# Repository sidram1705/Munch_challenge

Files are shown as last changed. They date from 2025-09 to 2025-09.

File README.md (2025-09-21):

# Munch_challenge

## Progress date: 14 Sept

### 1. Breadboard Circuit Assembly

After reviewing the datasheets of the motor driver and stm nucleo board, I noted the power requirements and pins that can be connected according to these requirements. This was the setup implemented by me:

| Pins | Connection | Reasoning |
| --- | --- | ---|
| EN | PA7 (STM32) | Enable pin just needs a digital High/Low, something we need to turn on and off the stepper motor to our exact rotation |
| MS1 | VCCIO (STM32) | The microstep pin connection would determines the multiplier for the angle of rotation. I decided to go with 16X by connecting both the pins to 5V|
| MS2 | VCCIO (STM32) | The microstep pin connection would determines the multiplier for the angle of rotation. I decided to go with 16X by connecting both the pins to 5V |
| Rx | x | Left floating because not using the UART mode of motor driver |
| Tx | x | Left floating because not using the UART mode of motor driver |
| CLK | x | Left floating because clock signals are for legacy motor drivers |
| STEP | PA5 (STM32) | Specifically chose the pin for the timer/counter functionality |
| DIR | PA6 (STM32) | Just a High/Low digital pin for the direction of rotation |
| VM | 12V | From the digital voltage source provided |
| GND | GND | Just grounding with the voltage source |
| A2 | Pin 1 (motor) | Four pins connecting the stepper motor to the motor driver |
| A1 | Pin 2 (motor) | Four pins connecting the stepper motor to the motor driver |
| B1 | Pin 3 (motor) | Four pins connecting the stepper motor to the motor driver |
| B2 | Pin 4 (motor) | Four pins connecting the stepper motor to the motor driver |
| VIO | VCC (STM32) | 5V from the MCU|
| GND | GND | From the MCU |

**NOTE**

A 100uF capacitor was added in series with the battery to act as a reservoir from the digital 12V and a 0.1uF was placed near the VS and GND pin to filter out high frequency noise. 

**Circuit Assembly**:

<div align=center>
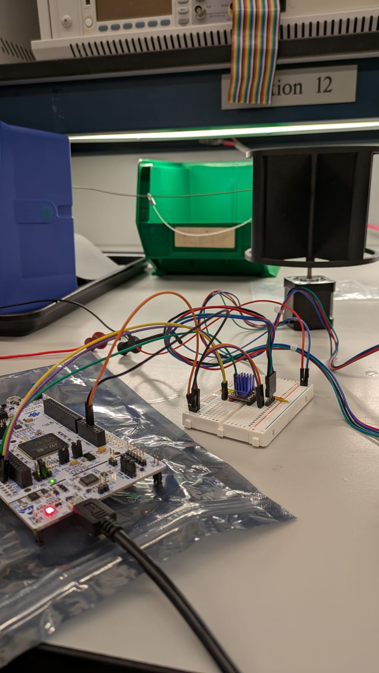
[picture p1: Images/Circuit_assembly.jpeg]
  
</div>

### 2. Schematic in KiCAD

The TMC2209 driver wasn't readily available from the existing drivers, so I created a symbol for the <a href="Munch_challenge/tmc2209.kicad_sym">motor driver</a>. 

**Motor Driver Symbol**

<div align=center>
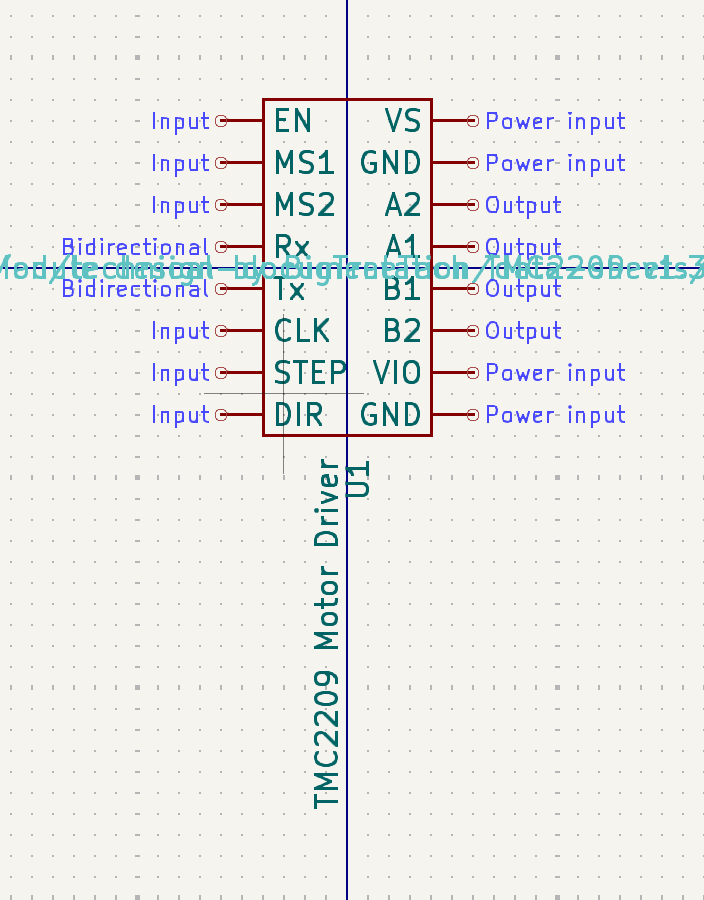
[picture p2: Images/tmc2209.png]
  
</div>

Using this symbol, I laid out the schematic based on the hardware assembly as mentioned above. The shcematic file is uploaded <a href="Munch_challenge/Munch_stepper_motor.kicad_sch">here</a>

**Schematic**

<div align=center>
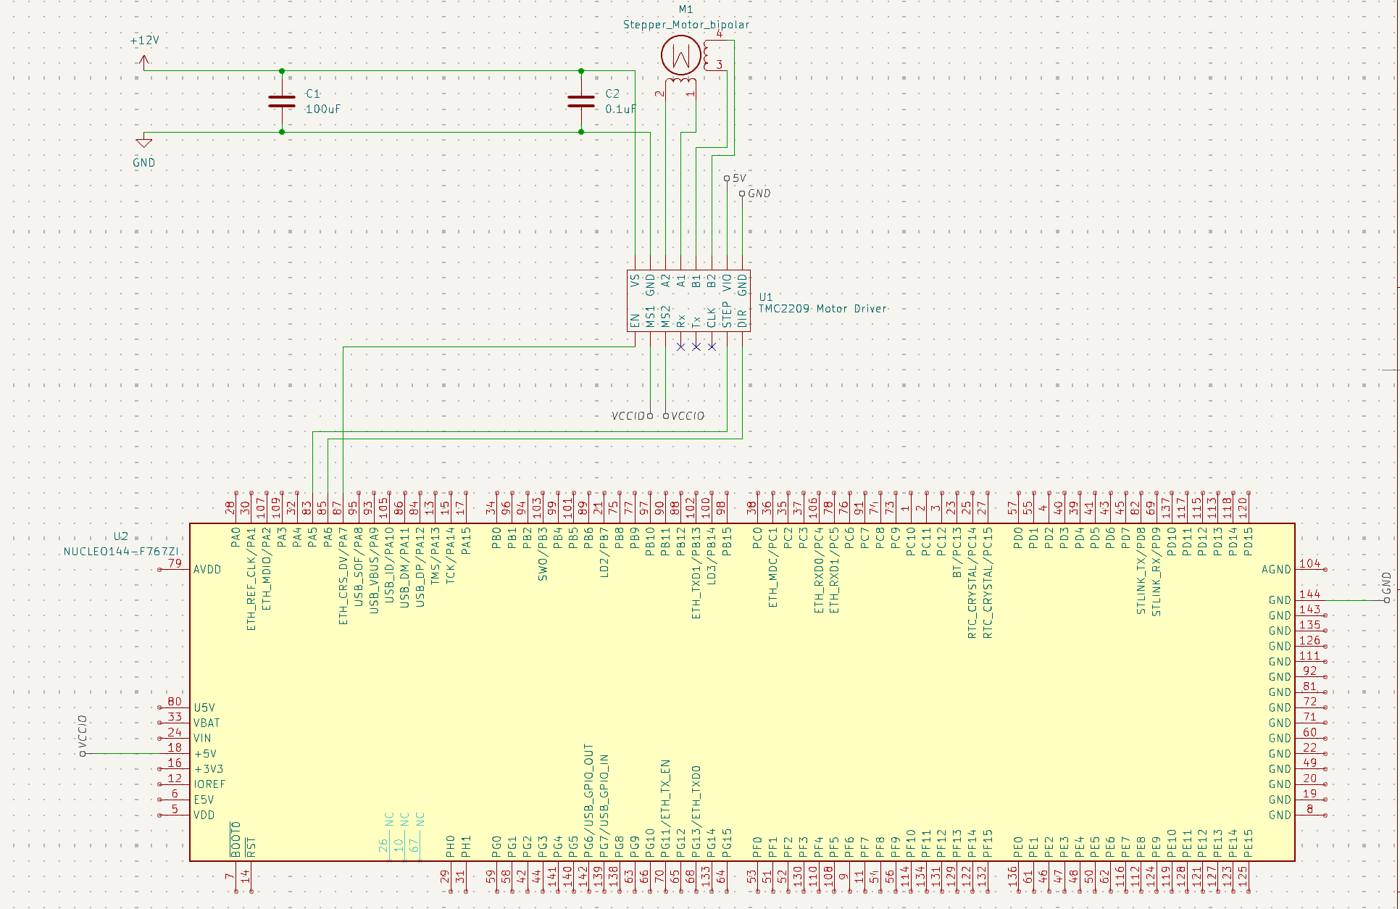
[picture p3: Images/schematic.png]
  
</div>

### 3.  Working Code

I wasn't able to setup the environment with zephyr to make the code run, so I tested it out first without zephyr using the STM32CubeIDE. The files that I ran the code on are linked in <a href="Munch_challenge/Inc">Inc</a> and <a href="Munch_challenge/Src">Src</a>. In order to make a working system for the stepper motor, I divided my file structure as follows:

- **delay module**: provides accurate microsecond delays using a hardware timer (TIMx).
- **stepper driver**: wraps STEP/DIR/EN control, angle→steps math, and motion primitives.
- **main**: initializes the HAL, clock, GPIO, timer, delay module, and the stepper; then runs your demo motions.

1. Delay:

System: HSI = 16 MHz, APB2 prescaler = DIV1 ⇒ timer_clk = 16 MHz.
TIM1 PSC = 215 (from your .ioc)

> f_cnt = 16,000,000 / (215 + 1) ≈ 74,074.07 Hz
> ticks = 500 × 74,074.07 / 1e6 ≈ 37.0 ticks  → wait until counter reaches ~37

2. Stepper:

- Init sets known-safe pin states and leaves the driver disabled by default.
- Enable/Disable toggles the EN pin respecting polarity.
- SetDir(dir) sets the DIR pin (driver samples DIR on the STEP edge; our delays are huge vs datasheet ns-scale constraints).
- StepN(n) performs n STEP pulses:
    - For each pulse:
        - Drive STEP high → wait step_pulse_us
        - Drive STEP low → wait step_space_us
    - Overall step period (µs):
    > T_step = step_pulse_us + step_space_us
    - Step frequency (Hz):
    > f_step = 1,000,000 / T_step

- AngleToSteps(angle_deg) converts degrees to microsteps using rounding (prevents cumulative error):
> steps = round( angle_deg × (full_steps_per_rev × microsteps) / 360 )

With 200 FSR and 1/16:
- 30° → 200×16×30/360 = 266.67 → 267 steps
- 45° → 200×16×45/360 = 400.00 → 400 steps
- 90° → 800 steps
- 180° → 1600 steps

- RotateAngle(angle_deg, dir) = set DIR → enable → StepN(AngleToSteps(...)) → disable.

3. Main:

    1. HAL & clocks: HAL_Init(), SystemClock_Config() (HSI 16 MHz in your project).
    2. GPIO & TIM1 init: CubeMX-generated MX_GPIO_Init() and MX_TIM1_Init() set:
        - STEP/DIR/EN as push-pull outputs.
        - TIM1 with your PSC (e.g., 215) and an ARR big enough to cover delays.
    3. Delay module: Delay_Init(&htim1, start=1)
        - Reads the actual timer clock + PSC and computes f_cnt for correct µs timing.
    4. Stepper config: Fill the StepperConfig with your pins, 200 steps/rev, 16 microsteps, and 500/500 µs pulse/space Initialize with an initial direction.
    5. Demo loop: Repeatedly call RotateAngle with 30°, 45°, 90°, 180° clockwise, sleeping 1 s between moves.

The working wideo can be viewed in <a href="/Images/Stepper_motor.mp4">Stepper_motor.mp4</a>

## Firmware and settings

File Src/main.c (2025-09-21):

#include "main.h"
#include "delay.h"
#include "stepper.h"

/* --- CubeMX-generated externs (keep your existing SystemClock_Config) --- */
TIM_HandleTypeDef htim1;

void SystemClock_Config(void);
static void MX_GPIO_Init(void);
static void MX_TIM1_Init(void);
void Error_Handler(void);

/* --- Your wiring (BTT TMC2209 v1.3 on GPIOA 5/6/7) --- */
#define STEP_PORT   GPIOA
#define STEP_PIN    GPIO_PIN_5
#define DIR_PIN     GPIO_PIN_6
#define EN_PIN      GPIO_PIN_7

int main(void)
{
    HAL_Init();
    SystemClock_Config();
    MX_GPIO_Init();
    MX_TIM1_Init();

    /* Initialize delay module on TIM1 (honors TIM1 PSC from your IOC) */
    Delay_Init(&htim1, 1 /* start timer */);

    /* Create stepper instance */
    StepperHandle motor;
    StepperConfig cfg = {
        .port               = STEP_PORT,
        .step_pin           = STEP_PIN,
        .dir_pin            = DIR_PIN,
        .en_pin             = EN_PIN,
        .en_active_low      = 1,         // TMC2209 ENN: low = enable
        .full_steps_per_rev = 200,
        .microsteps         = 16,        // MS1/MS2 high
        .step_pulse_us      = 500,       // high time
        .step_space_us      = 500        // low time -> 1 kHz total
    };

    Stepper_Init(&motor, &cfg, /*initial_dir=*/1);

    while (1)
    {
        Stepper_RotateAngle(&motor, 30.0f, 1);
        delay_ms(1000);

        Stepper_RotateAngle(&motor, 45.0f, 1);
        delay_ms(1000);

        Stepper_RotateAngle(&motor, 90.0f, 1);
        delay_ms(1000);

        Stepper_RotateAngle(&motor, 180.0f, 1);
        delay_ms(1000);
    }
}

/* -------------------- CubeMX areas (unchanged logic) -------------------- */

static void MX_TIM1_Init(void)
{
    /* Keep your existing generated code or the version we used earlier.
       Key point: Delay_Init() will read PSC and compute µs correctly. */

    TIM_ClockConfigTypeDef sClockSourceConfig = {0};
    TIM_MasterConfigTypeDef sMasterConfig = {0};

    __HAL_RCC_TIM1_CLK_ENABLE();

    htim1.Instance = TIM1;
    htim1.Init.Prescaler = 215; /* <- if this is what your IOC set; any value is OK */
    htim1.Init.CounterMode = TIM_COUNTERMODE_UP;
    htim1.Init.Period = 0xFFFF;
    htim1.Init.ClockDivision = TIM_CLOCKDIVISION_DIV1;
    htim1.Init.RepetitionCounter = 0;
    htim1.Init.AutoReloadPreload = TIM_AUTORELOAD_PRELOAD_DISABLE;
    if (HAL_TIM_Base_Init(&htim1) != HAL_OK) Error_Handler();

    sClockSourceConfig.ClockSource = TIM_CLOCKSOURCE_INTERNAL;
    if (HAL_TIM_ConfigClockSource(&htim1, &sClockSourceConfig) != HAL_OK) Error_Handler();

    sMasterConfig.MasterOutputTrigger  = TIM_TRGO_RESET;
    sMasterConfig.MasterOutputTrigger2 = TIM_TRGO2_RESET;
    sMasterConfig.MasterSlaveMode      = TIM_MASTERSLAVEMODE_DISABLE;
    if (HAL_TIMEx_MasterConfigSynchronization(&htim1, &sMasterConfig) != HAL_OK) Error_Handler();
}

static void MX_GPIO_Init(void)
{
    __HAL_RCC_GPIOA_CLK_ENABLE();

    GPIO_InitTypeDef io = {0};
    HAL_GPIO_WritePin(STEP_PORT, STEP_PIN | DIR_PIN | EN_PIN, GPIO_PIN_RESET);

    io.Pin   = STEP_PIN | DIR_PIN | EN_PIN;
    io.Mode  = GPIO_MODE_OUTPUT_PP;
    io.Pull  = GPIO_NOPULL;
    io.Speed = GPIO_SPEED_FREQ_LOW;
    HAL_GPIO_Init(STEP_PORT, &io);
}

/* Keep your SystemClock_Config() and Error_Handler() from before */


/* -------------------- Clock (HSI @ 16 MHz) -------------------- */

void SystemClock_Config(void)
{
    RCC_OscInitTypeDef RCC_OscInitStruct = {0};
    RCC_ClkInitTypeDef RCC_ClkInitStruct = {0};

    __HAL_RCC_PWR_CLK_ENABLE();
    __HAL_PWR_VOLTAGESCALING_CONFIG(PWR_REGULATOR_VOLTAGE_SCALE3);

    RCC_OscInitStruct.OscillatorType = RCC_OSCILLATORTYPE_HSI;
    RCC_OscInitStruct.HSIState = RCC_HSI_ON;
    RCC_OscInitStruct.HSICalibrationValue = RCC_HSICALIBRATION_DEFAULT;
    RCC_OscInitStruct.PLL.PLLState = RCC_PLL_NONE;
    if (HAL_RCC_OscConfig(&RCC_OscInitStruct) != HAL_OK) Error_Handler();

    RCC_ClkInitStruct.ClockType = RCC_CLOCKTYPE_HCLK|RCC_CLOCKTYPE_SYSCLK|
                                  RCC_CLOCKTYPE_PCLK1|RCC_CLOCKTYPE_PCLK2;
    RCC_ClkInitStruct.SYSCLKSource   = RCC_SYSCLKSOURCE_HSI;
    RCC_ClkInitStruct.AHBCLKDivider  = RCC_SYSCLK_DIV1;
    RCC_ClkInitStruct.APB1CLKDivider = RCC_HCLK_DIV1;
    RCC_ClkInitStruct.APB2CLKDivider = RCC_HCLK_DIV1;
    if (HAL_RCC_ClockConfig(&RCC_ClkInitStruct, FLASH_LATENCY_0) != HAL_OK) Error_Handler();
}

/* -------------------- Error handler -------------------- */

void Error_Handler(void)
{
    __disable_irq();
    while (1) { }
}

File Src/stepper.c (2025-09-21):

#include "stepper.h"
#include "delay.h"   // uses delay_us()

static inline void write_en(const StepperHandle *h, GPIO_PinState state)
{
    if (h->cfg.en_pin == 0) return; // no EN line wired
    HAL_GPIO_WritePin(h->cfg.port, h->cfg.en_pin, state);
}

void Stepper_Init(StepperHandle *h, const StepperConfig *cfg, uint8_t initial_dir)
{
    h->cfg = *cfg;
    h->dir = (initial_dir != 0);

    /* Caller is responsible for enabling GPIO clock and configuring pins
       (or do it here if you want the driver to own it).
       We’ll just drive them to safe defaults. */
    HAL_GPIO_WritePin(h->cfg.port, h->cfg.step_pin | h->cfg.dir_pin, GPIO_PIN_RESET);

    /* Disable driver by default */
    if (h->cfg.en_pin) {
        GPIO_PinState idle = h->cfg.en_active_low ? GPIO_PIN_SET : GPIO_PIN_RESET;
        write_en(h, idle);
    }
}

void Stepper_Enable(StepperHandle *h)
{
    if (!h->cfg.en_pin) return;
    GPIO_PinState on = h->cfg.en_active_low ? GPIO_PIN_RESET : GPIO_PIN_SET;
    write_en(h, on);
}

void Stepper_Disable(StepperHandle *h)
{
    if (!h->cfg.en_pin) return;
    GPIO_PinState off = h->cfg.en_active_low ? GPIO_PIN_SET : GPIO_PIN_RESET;
    write_en(h, off);
}

void Stepper_SetDir(StepperHandle *h, uint8_t dir)
{
    h->dir = (dir != 0);
    HAL_GPIO_WritePin(h->cfg.port, h->cfg.dir_pin, h->dir ? GPIO_PIN_SET : GPIO_PIN_RESET);
    /* DIR setup time is tiny on TMC2209; our delays far exceed it. */
}

void Stepper_StepN(StepperHandle *h, uint16_t steps)
{
    /* Ensure direction pin is already set */
    for (uint16_t i = 0; i < steps; i++)
    {
        HAL_GPIO_WritePin(h->cfg.port, h->cfg.step_pin, GPIO_PIN_SET);
        delay_us(h->cfg.step_pulse_us);
        HAL_GPIO_WritePin(h->cfg.port, h->cfg.step_pin, GPIO_PIN_RESET);
        delay_us(h->cfg.step_space_us);
    }
}

uint16_t Stepper_AngleToSteps(const StepperHandle *h, float angle_deg)
{
    float steps_f = angle_deg * (h->cfg.full_steps_per_rev * h->cfg.microsteps) / 360.0f;
    uint32_t total_steps = (uint32_t)(steps_f + 0.5f);
    if (total_steps > UINT16_MAX) total_steps = UINT16_MAX;
    return (uint16_t)total_steps;
}

void Stepper_RotateAngle(StepperHandle *h, float angle_deg, uint8_t dir)
{
    Stepper_SetDir(h, dir);
    Stepper_Enable(h);
    Stepper_StepN(h, Stepper_AngleToSteps(h, angle_deg));
    Stepper_Disable(h);
}
